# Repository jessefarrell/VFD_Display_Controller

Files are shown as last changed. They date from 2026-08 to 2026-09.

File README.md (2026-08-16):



<!-- PROJECT LOGO -->
<br />
<div align="center">
  <a href="https://github.com/othneildrew/Best-README-Template">
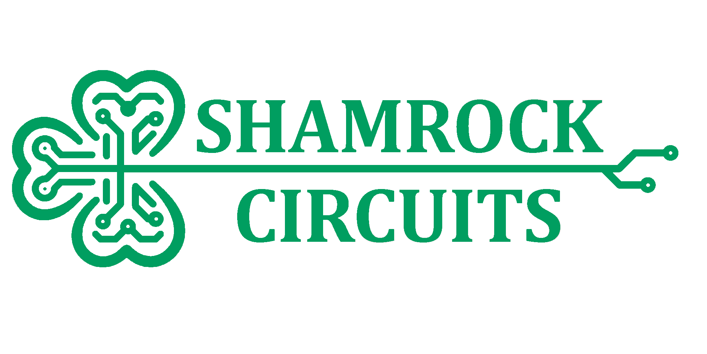
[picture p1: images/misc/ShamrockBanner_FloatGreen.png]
    
  </a>

  <h1 align="center">VFD Module Controller - REV00</h1>

  <p align="center">
    The <a href="https://ckm-content.se.com/ckmContent/sfc/servlet.shepherd/document/download/0691H00000GYmavQAD">Power Measurement, ACM 3710</a> was a power meter released in 1989 which was discontinued in the "early 2000s".<br />
    These meters used an interesting, semi-custom, 20 character, 14 segment, Vacuum Fluorescent Display.
    <br />
    I have five of these VFD modules floating around my parts bin... so I made this controller board to interfce with them.
    <br />
    <br />
    <strong>STATUS - IN PROGRESS</strong>
    <br />
    <a href="https://youtube.com">View Demo</a> [PENDING]

  </p>
</div>

## Introduction
<!-- High level overview of what the project is and does -->
This VFD module controller was designed around a VFD module that was originally integrated into the <a href="https://ckm-content.se.com/ckmContent/sfc/servlet.shepherd/document/download/0691H00000GYmavQAD">ACM 3710</a>. Exact model numbers of the module seem to vary, but as far as I can tell they are all interchangeable. This module is the **ISE Electronics Corp, FU209SCPB-S4A** or **FU209SCPB-T60A**, and they seem to be a custom (undocumented) model that is similar to  **CU209SCPB-T20A**. The purpose of this project is to convert the VFD modules parallel bus interface into something configurable over USB, and to possible develop a few applications for the display.
<p align="center">
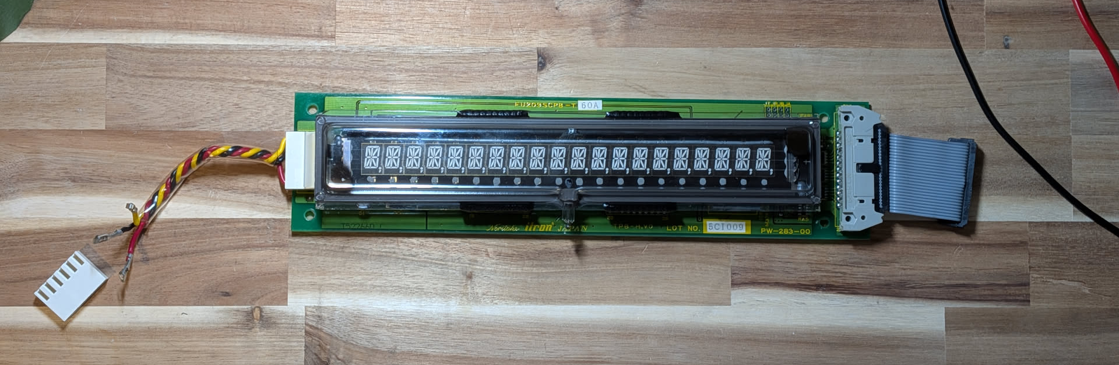
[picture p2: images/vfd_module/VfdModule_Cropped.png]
  
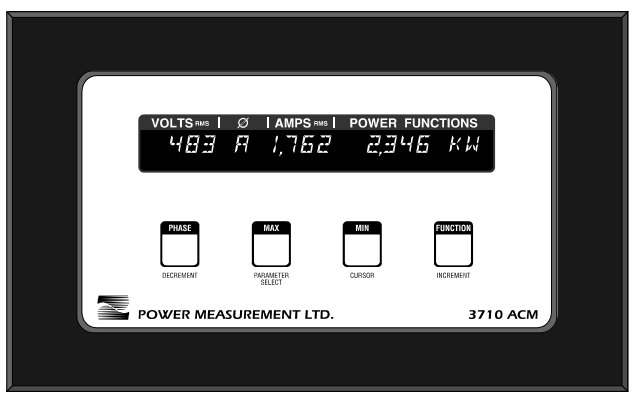
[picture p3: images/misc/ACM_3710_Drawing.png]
ACM 3710
  
</p>

## Motivation
<!-- Why I bothered making this -->
I'm a sucker for 7-segment displays and other interesting displays in general. So 14 segments on a VFD easily got my attention from the bin. A short dumpster dive later I found myself the proud owner of 5 VFD modules. All of the hard work of interfacing with the display is managed by the module, but I still need a way of controlling the 8bit data bus from the comfort of my desk. The fact that so much of the work has been offloaded onto the VFD module itself, makes this whole thing a good candidate for a "quick weekend project"...

## Features
- USB Serial Control
- Command Line Interface
- Write Character or String
- Shift Displayed String
- Delete Character
- Clear Screen

## How it Works
<!-- IMAGE: Block diagram -->
This project could, in theory, be as simple as a microcontroller driving the various I/O pins of the VFD module. The module itself consumes about 430-460mA during normal operation, from a single 5V power input (the module then converts that to a higher voltage for the VFD), leaving just enough headroom in the 500mA (5 unit load) USB spec to power the controller board I'm designing. Some flavour of AVR microcontroller would have been a good fit here, but my bin full of Pi Pico's is looking for a project, meaning I'll need some logic level translators. I also decided to include an optional barrel jack power input incase I want to stack multiple VFD modules together, or if the USB port isn't able to provide the 500mA.
<br />
<br />
Instead of providing a block diagram, this project is small enough to just review the schematic (shown below).
<p align="center">
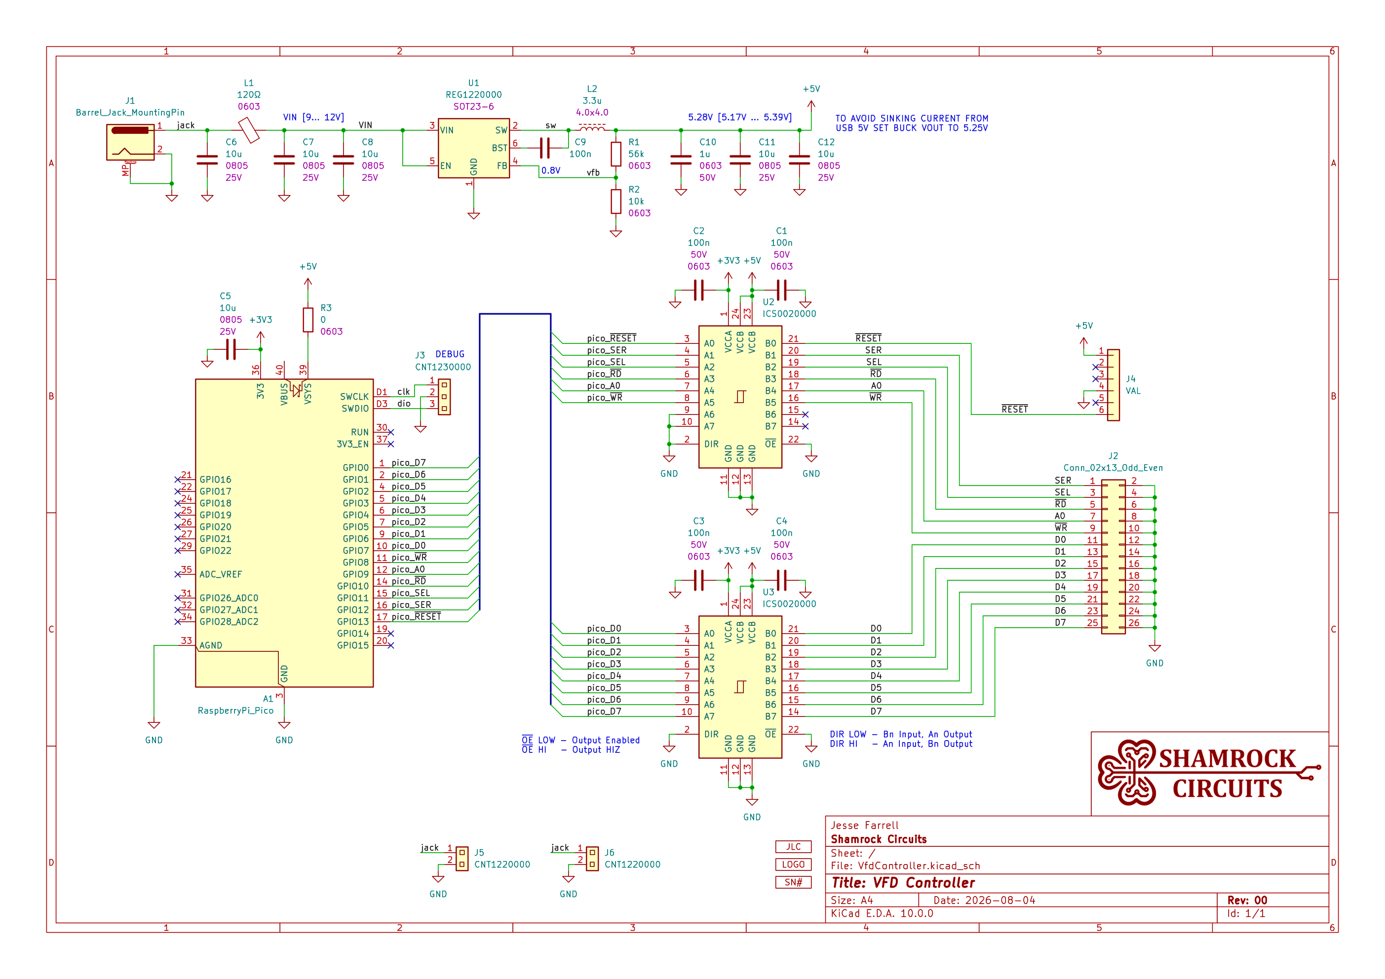
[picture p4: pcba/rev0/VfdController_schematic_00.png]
Schematic Image
  
</p>

## Gallery

<!-- IMAGE: 2-3 supporting shots — schematic snippet, PCB layout, alternate angle render -->
<p float="left">
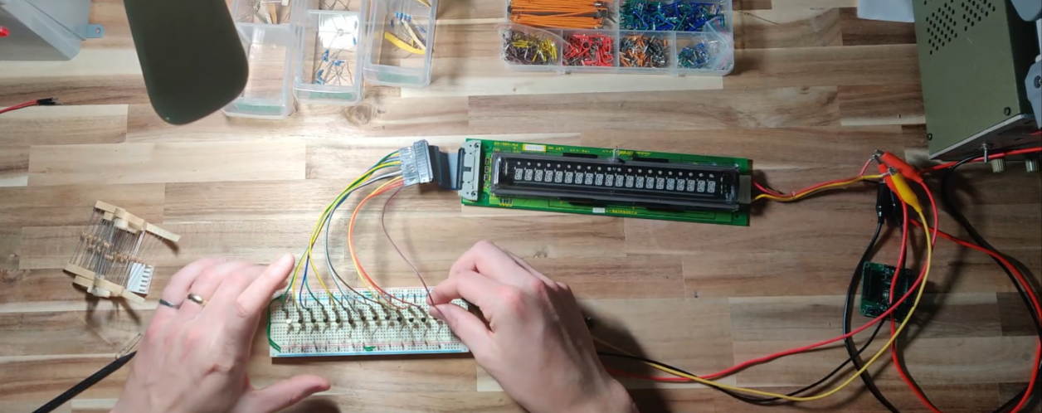
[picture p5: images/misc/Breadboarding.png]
  
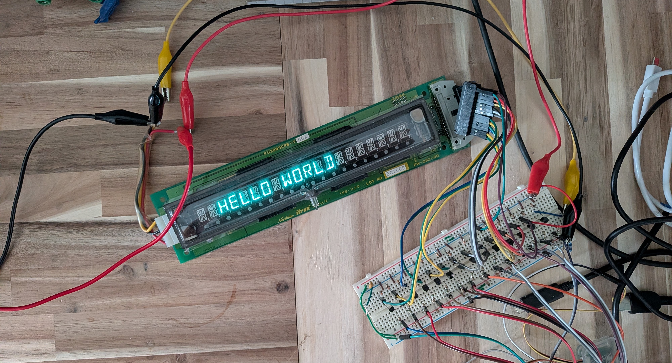
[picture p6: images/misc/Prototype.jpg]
PCB bottom layout
  
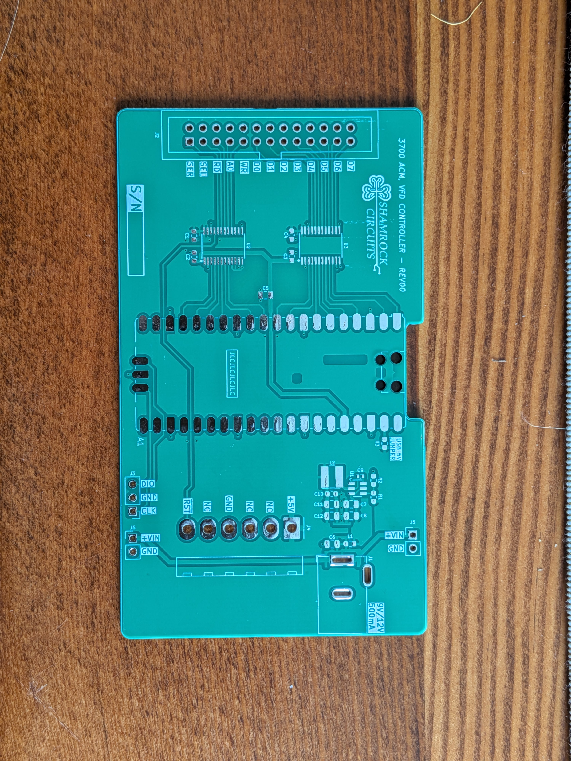
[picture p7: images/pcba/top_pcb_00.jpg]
  
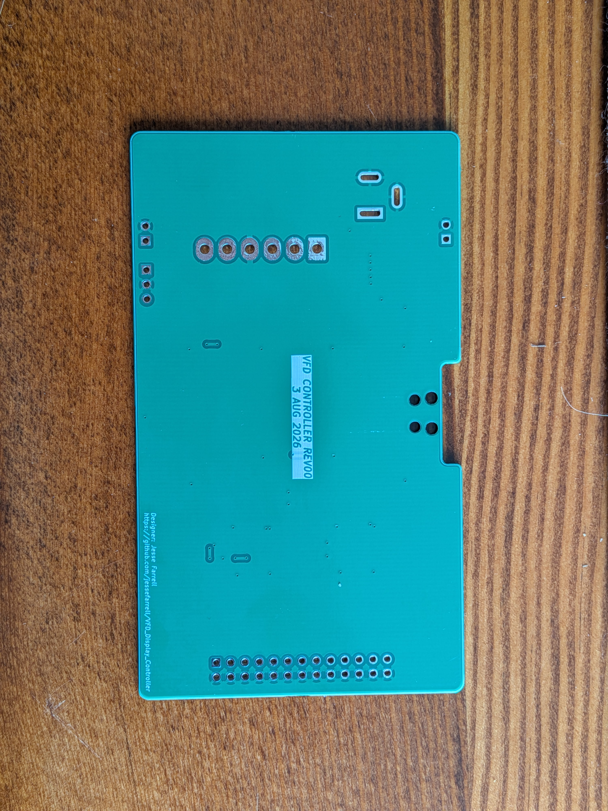
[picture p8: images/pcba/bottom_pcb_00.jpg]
  
</p>

## Status
I received PCBs 8/16/2026, and I recently ordered the connectors. This project will probably be closed later this month.

## License



---

Designed by Jesse Farrell — [info@shamrockcircuits.com](mailto:info@shamrockcircuits.com)

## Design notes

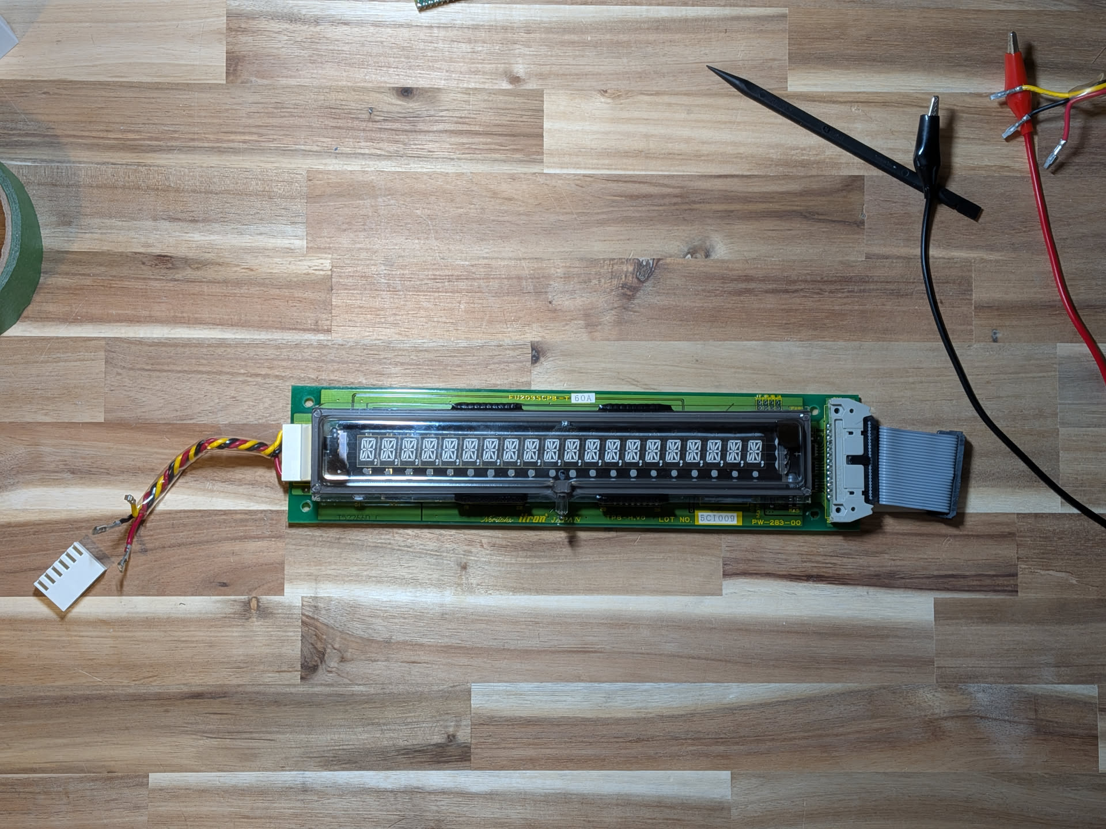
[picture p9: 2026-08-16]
images/vfd_module/VfdModule.png

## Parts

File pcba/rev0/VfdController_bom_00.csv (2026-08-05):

IPN | Reference | Qty | Value | Exclude from BOM | Footprint | Package | MFN_1 | MPN_1 | LCSC_1
N/A | A1 | 1 | RaspberryPi_Pico |  | Module:RaspberryPi_Pico_SMD_HandSolder
CAP-000-1042 | C1,C2,C3,C4 | 4 | 100n |  | 0-CAP:FTP-CAP-0001 | 603 | Samsung | CC0603KRX7R9BB104 | C14663, BASIC
CAP-007-1061 | C5,C6,C7,C8,C11,C12 | 6 | 10u |  | 0-CAP:FTP-CAP-0002 | 805 | Samsung | CL21A106KAYNNNE | C15850
CAP-001-1042 | C9 | 1 | 100n |  | 0-CAP:FTP-CAP-0000 | 402 | Samsung | CL05B104KB54PNC | C307331
CAP-003-1051 | C10 | 1 | 1u |  | 0-CAP:FTP-CAP-0001 | 603 | Samsung | CL10A105KB8NNNC | C15849
N/A | J1 | 1 | Barrel_Jack_MountingPin |  | Connector_BarrelJack:BarrelJack_GCT_DCJ200-10-A_Horizontal
N/A | J2 | 1 | Conn_02x13_Odd_Even |  | Connector_IDC:IDC-Header_2x13_P2.54mm_Vertical
CNT-123-0000 | J3 | 1 | CNT1230000 |  | 0-CNT:FTP-CNT-0008 |  | Molex | 22284030 | C587036, EXT
N/A | J4 | 1 | VAL |  | Connector_Molex:Molex_KK-396_A-41792-0006_1x06_P3.96mm_Horizontal
CNT-122-0000 | J5,J6 | 2 | CNT1220000 |  | 0-CNT:FTP-CNT-0007 |  | Molex | 22284020 | C234182, EXT
IND-203-1202 | L1 | 1 | 120Ω |  | 0-IND:FTP-IND-0002 | 603 | Murata | BLM18PG121SN1D | C14709
IND-002-3304 | L2 | 1 | 3.3u |  | 0-IND:FTP-IND-0000 | 4.0x4.0 | Vishay | VLS4020CX-3R3M-H | C6745793
RES-006-5604 | R1 | 1 | 56k |  | 0-RES:FTP-RES-0001 | 603 | Stackpole Electronics | RNCF0603BTE56K0 | C3958730
RES-006-1004 | R2 | 1 | 10k |  | 0-RES:FTP-RES-0001 | 603 | Stackpole Electronics | RNCF0603BTE10K0 | C346560
RES-000-0000 | R3 | 1 | 0 |  | 0-RES:FTP-RES-0001 | 603 | UNI-ROYAL | 0603WAF0000T5E | C21189, BASIC
REG-122-0000 | U1 | 1 | REG1220000 |  | 1-PACKAGES:Generic-SOT23-6 | SOT23-6 | Diodes Inc. | AP62150WU* | C3194237
ICS-002-0000 | U2,U3 | 2 | ICS0020000 |  | 1-PACKAGES:Generic-TSSOP-24_4.4x7.8mm_P0.65mm | TSSOP-24 (4.40mm) | Nexperia | 74LVC4245APW,118 | C6091, EXT

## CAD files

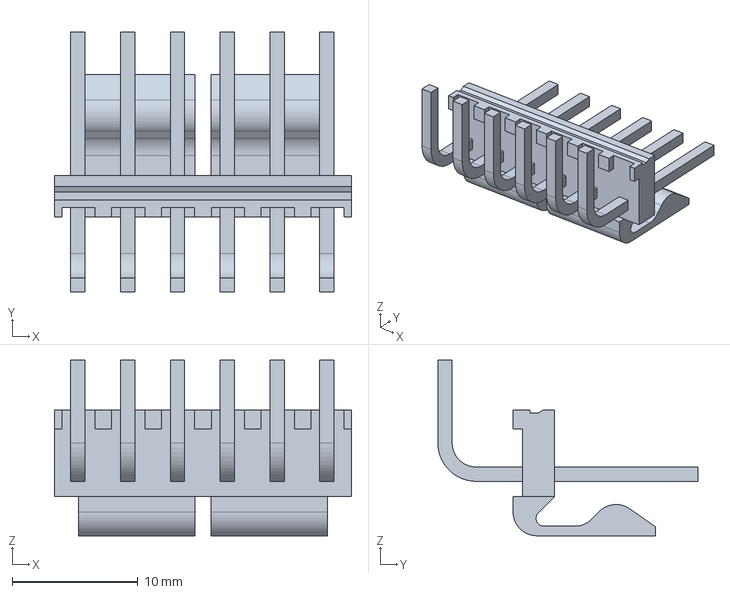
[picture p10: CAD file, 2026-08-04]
3dmodels/Components/6Pin_Molex.stp
23.6 x 20.7 x 14.0 mm

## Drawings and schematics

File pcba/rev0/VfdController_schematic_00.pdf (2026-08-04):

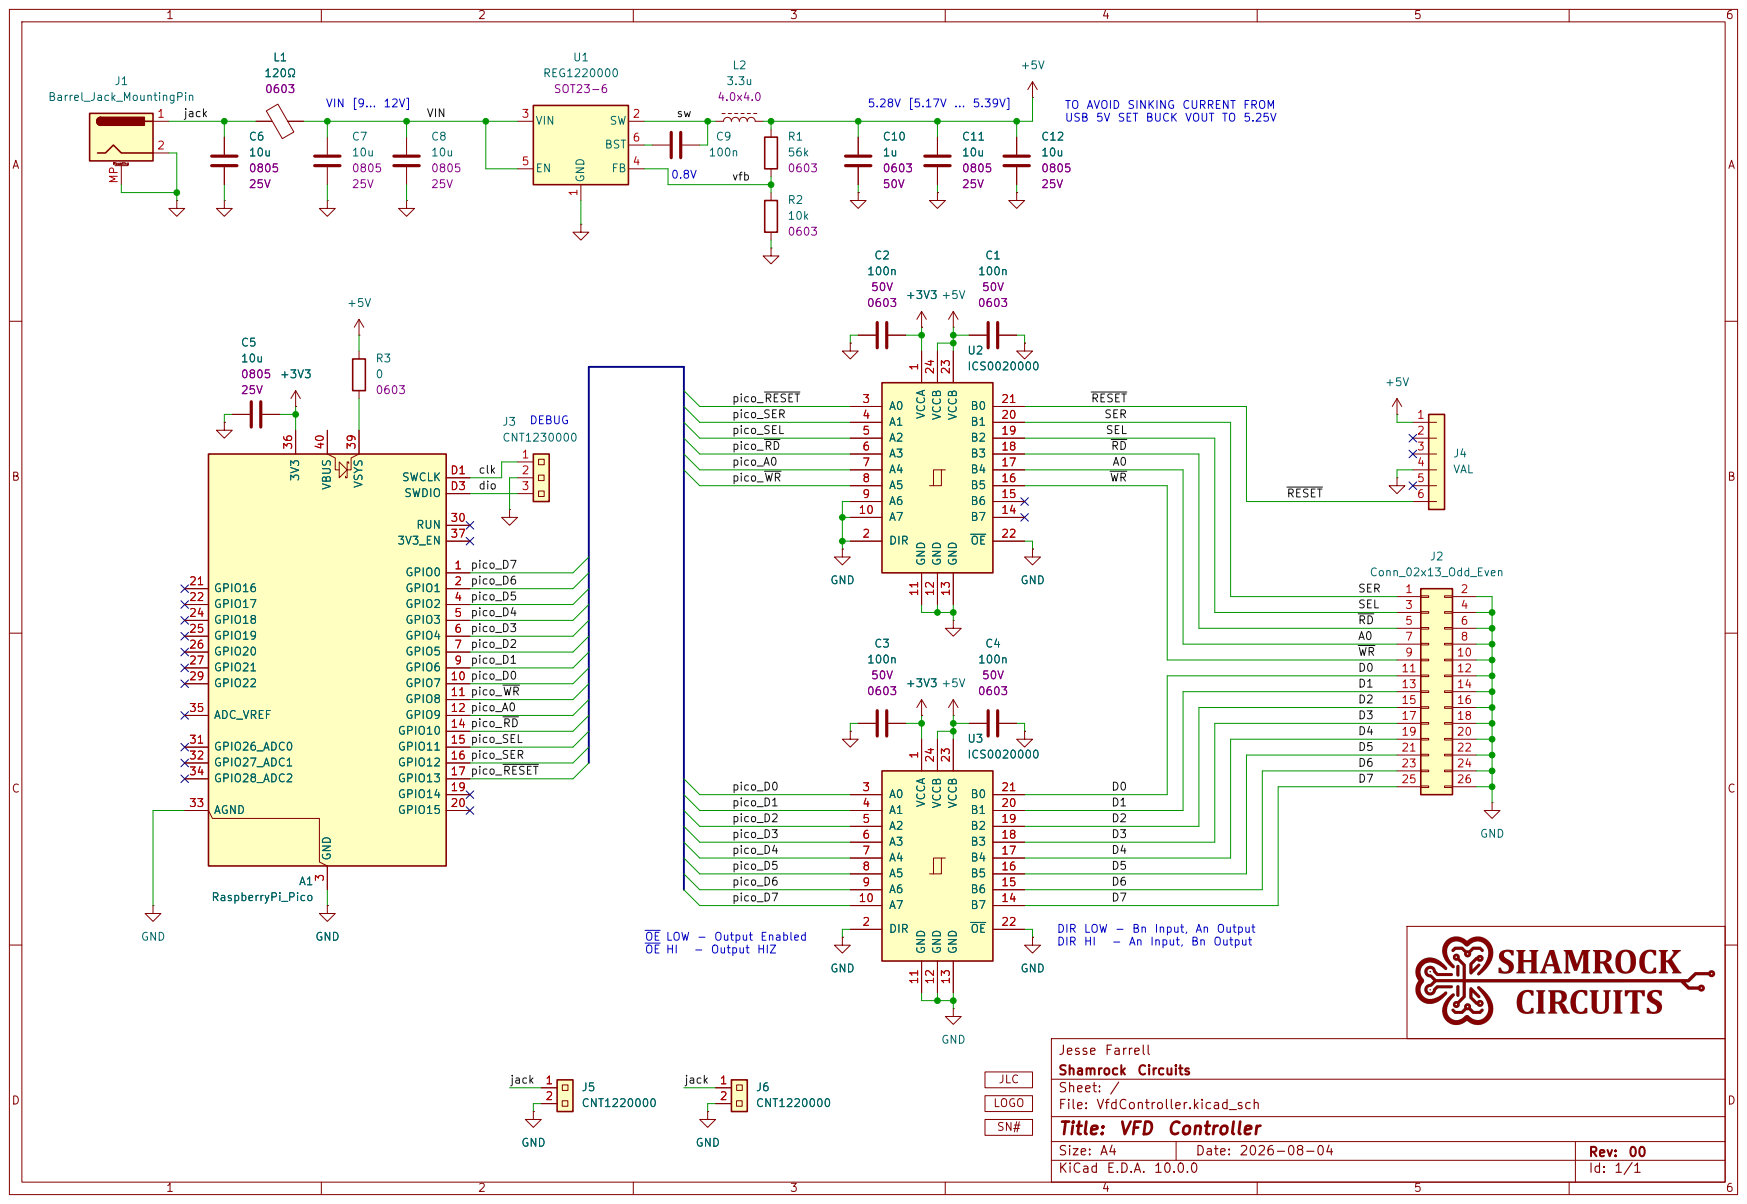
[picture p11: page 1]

TO AVOID SINKING CURRENT FROM
USB 5V SET BUCK VOUT TO 5.25V

13 | 14
15 | 16
17 | 18
19 | 20
21 | 22
23 | 24

DIR LOW - Bn Input, An Output

Size: A4 | Rev: 00

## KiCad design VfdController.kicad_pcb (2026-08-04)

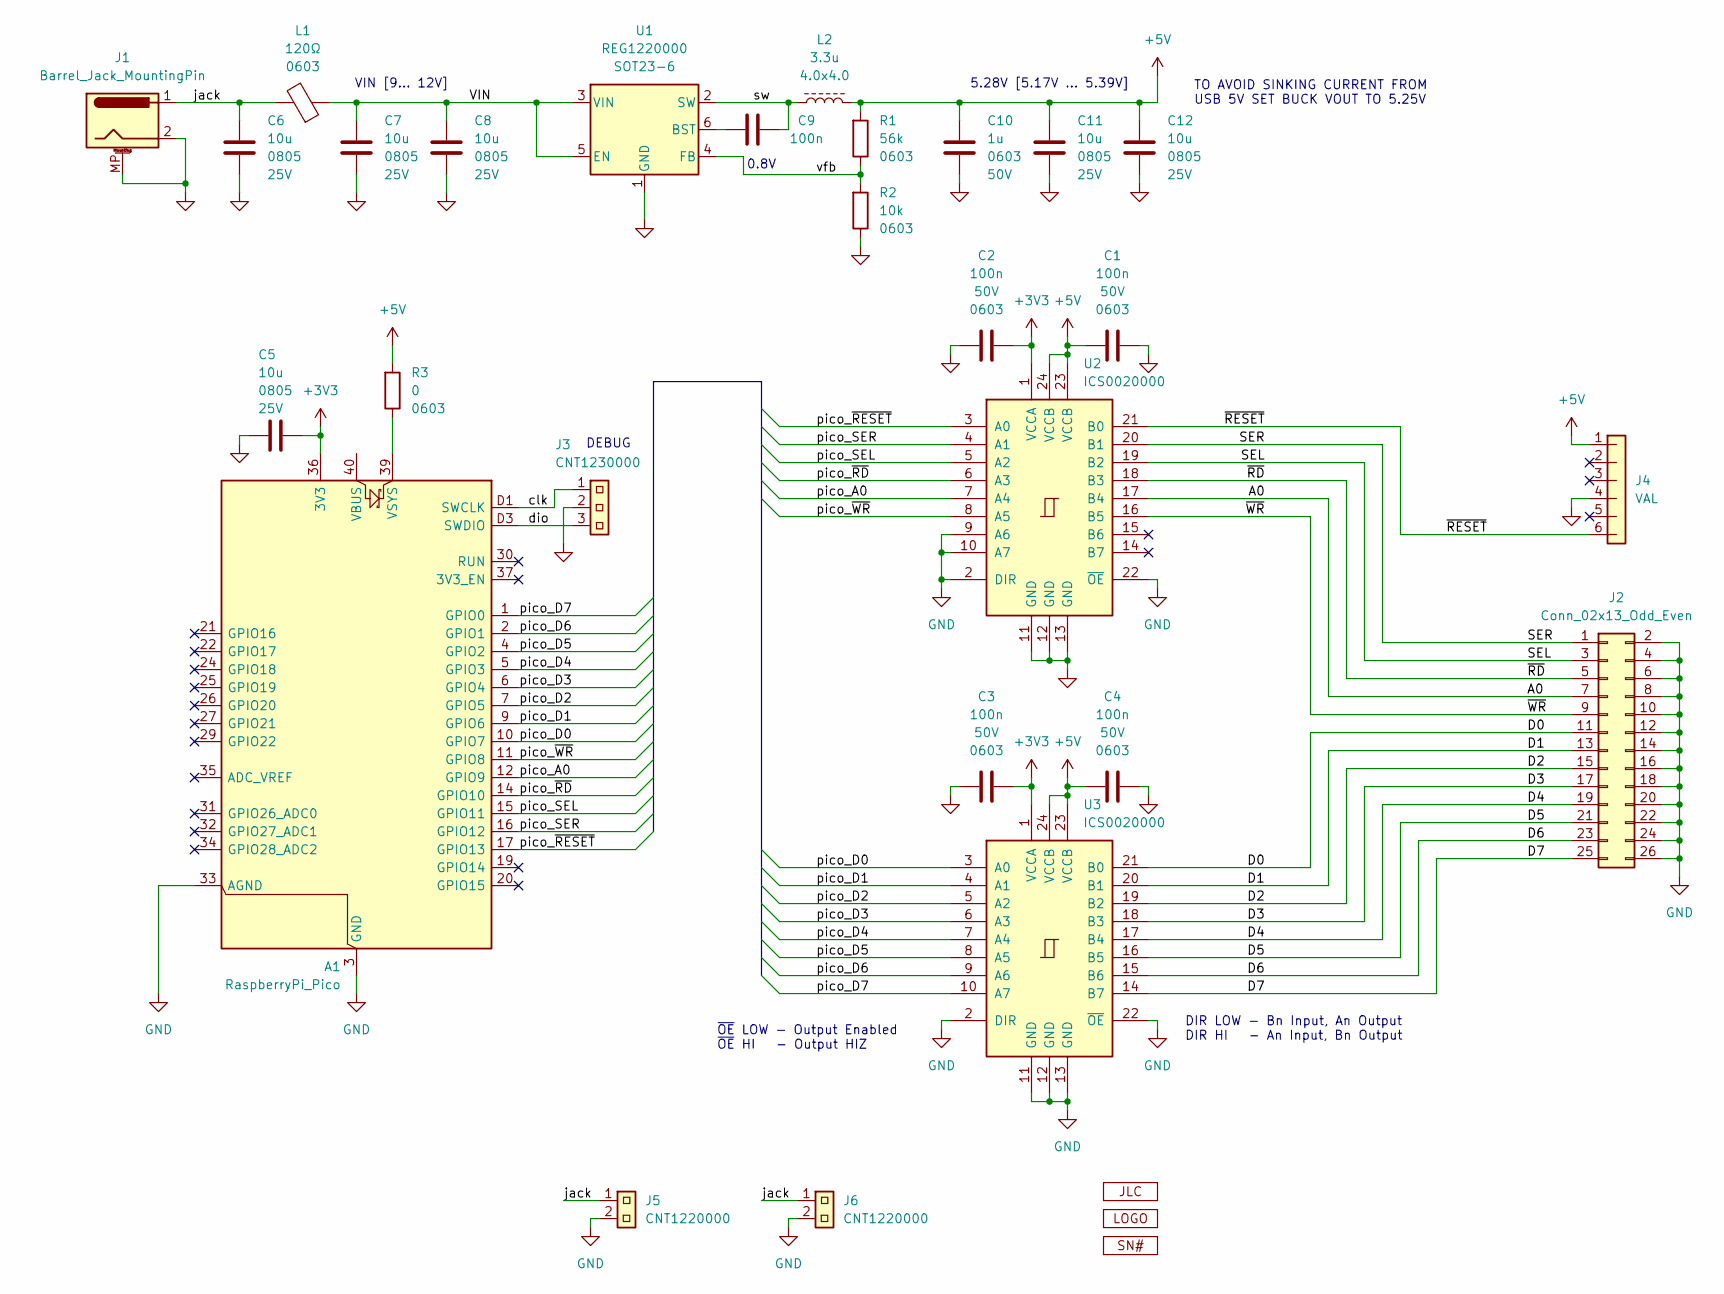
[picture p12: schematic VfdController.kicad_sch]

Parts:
A1: RaspberryPi_Pico; RaspberryPi_Pico_SMD_HandSolder
C1, C2, C3, C4: 100n; FTP-CAP-0001; Voltage Rating 50V; MPN_1 CC0603KRX7R9BB104; LCSC_1 C14663, BASIC
C5, C6, C7, C8, C11, C12: 10u; FTP-CAP-0002; Voltage Rating 25V; MPN_1 CL21A106KAYNNNE; LCSC_1 C15850
C9: 100n; FTP-CAP-0000; Voltage Rating 50V; MPN_1 CL05B104KB54PNC; LCSC_1 C307331
C10: 1u; FTP-CAP-0001; Voltage Rating 50V; MPN_1 CL10A105KB8NNNC; LCSC_1 C15849
G1: FTP-MRK-0002b
G2: FTP-MRK-0000
G3: FTP-MRK-0003
J1: Barrel_Jack_MountingPin; BarrelJack_GCT_DCJ200-10-A_Horizontal
J2: Conn_02x13_Odd_Even; IDC-Header_2x13_P2.54mm_Vertical
J3: CNT1230000; FTP-CNT-0008; MPN_1 22284030; LCSC_1 C587036, EXT
J4: VAL; Molex_KK-396_A-41792-0006_1x06_P3.96mm_Horizontal
J5, J6: CNT1220000; FTP-CNT-0007; MPN_1 22284020; LCSC_1 C234182, EXT
L1: 120Ω; FTP-IND-0002; MPN_2 742792625; LCSC_1 C14709
L2: 3.3u; FTP-IND-0000; MPN_3 AWVF004040183R3M00; LCSC_3 C17220294
R1: 56k; FTP-RES-0001; MPN_1 RNCF0603BTE56K0; LCSC_1 C3958730
R2: 10k; FTP-RES-0001; MPN_1 RNCF0603BTE10K0; LCSC_1 C346560
R3: 0; FTP-RES-0001; MPN_1 0603WAF0000T5E; LCSC_1 C21189, BASIC
U1: REG1220000; Generic-SOT23-6; MPN_1 AP62150WU*; LCSC_1 C3194237
U2, U3: ICS0020000; Generic-TSSOP-24_4.4x7.8mm_P0.65mm; MPN_1 74LVC4245APW,118; LCSC_1 C6091, EXT

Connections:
+3V3: A1.36 (3V3), C2.2, C3.2, C5.1, U2.1 (VCCA), U3.1 (VCCA)
+5V: C1.1, C4.1, C10.1, C11.1, C12.1, J4.1, L2.2, R1.1, R3.1, U2.23 (VCCB), U2.24 (VCCB), U3.23 (VCCB), U3.24 (VCCB)
/A0: J2.7, U2.17 (B4)
/D0: J2.11, U3.21 (B0)
/D1: J2.13, U3.20 (B1)
/D2: J2.15, U3.19 (B2)
/D3: J2.17, U3.18 (B3)
/D4: J2.19, U3.17 (B4)
/D5: J2.21, U3.16 (B5)
/D6: J2.23, U3.15 (B6)
/D7: J2.25, U3.14 (B7)
/SEL: J2.3, U2.19 (B2)
/SER: J2.1, U2.20 (B1)
/VIN: C7.1, C8.1, L1.1, U1.3 (VIN), U1.5 (EN)
/clk: A1.D1 (SWCLK), J3.1
/dio: A1.D3 (SWDIO), J3.3
/jack: C6.1, J1.1, J5.1, J6.1, L1.2
/pico_A0: A1.12 (GPIO9), U2.7 (A4)
/pico_D0: A1.10 (GPIO7), U3.3 (A0)
/pico_D1: A1.9 (GPIO6), U3.4 (A1)
/pico_D2: A1.7 (GPIO5), U3.5 (A2)
/pico_D3: A1.6 (GPIO4), U3.6 (A3)
/pico_D4: A1.5 (GPIO3), U3.7 (A4)
/pico_D5: A1.4 (GPIO2), U3.8 (A5)
/pico_D6: A1.2 (GPIO1), U3.9 (A6)
/pico_D7: A1.1 (GPIO0), U3.10 (A7)
/pico_SEL: A1.15 (GPIO11), U2.5 (A2)
/pico_SER: A1.16 (GPIO12), U2.4 (A1)
/pico_~RD: A1.14 (GPIO10), U2.6 (A3)
/pico_~RESET: A1.17 (GPIO13), U2.3 (A0)
/pico_~WR: A1.11 (GPIO8), U2.8 (A5)
/sw: C9.1, L2.1, U1.2 (SW)
/vfb: R1.2, R2.1, U1.4 (FB)
/~RD: J2.5, U2.18 (B3)
/~RESET: J4.6, U2.21 (B0)
/~WR: J2.9, U2.16 (B5)
GND: A1.3 (GND), A1.8 (GND), A1.13 (GND), A1.18 (GND), A1.23 (GND), A1.28 (GND), A1.33 (AGND), A1.38 (GND), A1.D2 (GND), C1.2, C2.1, C3.1, C4.2, C5.2, C6.2, C7.2, C8.2, C10.2, C11.2, C12.2, J1.2, J1.MP (MountPin_MP), J2.2, J2.4, J2.6, J2.8, J2.10, J2.12, J2.14, J2.16, J2.18, J2.20, J2.22, J2.24, J2.26, J3.2, J4.4, J5.2, J6.2, R2.2, U1.1 (GND), U2.2 (DIR), U2.9 (A6), U2.10 (A7), U2.11 (GND), U2.12 (GND), U2.13 (GND), U2.22 (~OE), U3.2 (DIR), U3.11 (GND), U3.12 (GND), U3.13 (GND), U3.22 (~OE)
unnamed: A1.39 (VSYS), R3.2
unnamed: C9.2, U1.6 (BST)

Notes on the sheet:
DIR LOW - Bn Input, An Output DIR HI - An Input, Bn Output
5.28V [5.17V ... 5.39V]
DEBUG
0.8V
~{OE} LOW - Output Enabled ~{OE} HI - Output HIZ
TO AVOID SINKING CURRENT FROM USB 5V SET BUCK VOUT TO 5.25V
VIN [9... 12V]

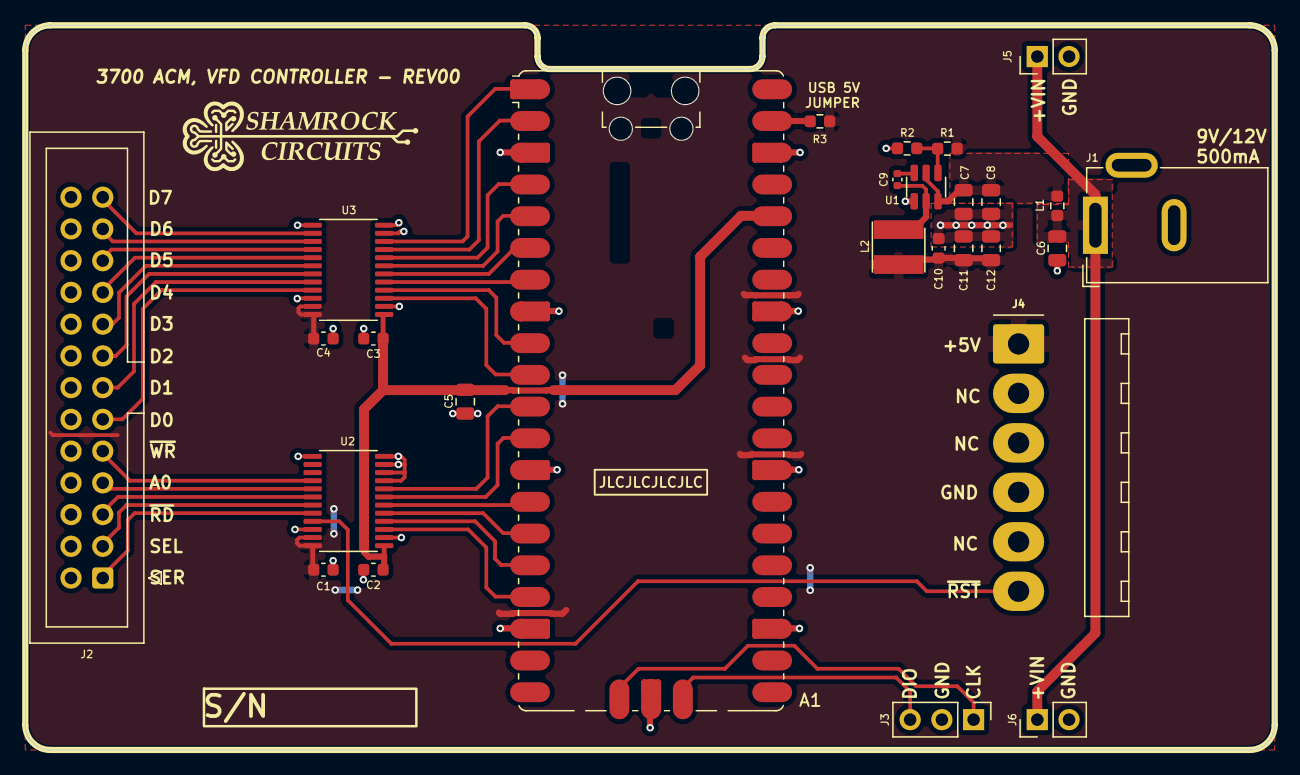
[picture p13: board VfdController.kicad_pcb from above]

Board: 2 copper layers, 100.0 x 58.0 mm, 30 parts (0 on the bottom side), 39 nets.

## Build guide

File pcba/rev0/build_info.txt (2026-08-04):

__General Notes__
04/08/2026 - Ordered 10x PCBA. 1oz copper, lead free HASL, 1.6mm, ect.

__Details__
PCB FAB	--------> JLCPCB
Layers ---------> 2L
Stackup Used ---> Default

__Build Table__
|Build Date	| BOM Used	| Comments	  				|
|---|---|---|
|04/08/2026	| n/a		| Hand assembling these boards.			|
|dd/mm/yy	| xxx.csv	| build notes...				|
|---------------|---------------|-----------------------------------------------|

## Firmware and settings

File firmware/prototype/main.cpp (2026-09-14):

/**
 * Copyright (c) 2020 Raspberry Pi (Trading) Ltd.
 *
 * SPDX-License-Identifier: BSD-3-Clause
 */

#include "pico/stdlib.h"
#include "pico/stdio.h"
#include "config.h"
#include "vfd.h"
#include "clock.h"
#include "test_display.h"
#include "animation.h"
#include <stdio.h>

// Single global instance, shared by whichever app the user selects below.
Vfd vfd(SETUP_HOLD_TIME_US);

/**
 * @brief Blocking read of one character from stdin, echoed back to console.
 */
static char read_char(void) {
    int c = getchar_timeout_us(UINT32_MAX);  // block indefinitely

    if (c == PICO_ERROR_TIMEOUT) {
        return '\0';  // shouldn't happen with UINT32_MAX, but just in case
    }

    putchar((char)c);
    return (char)c;
}

static void print_app_menu(void) {
    printf("\n--- VFD Launcher ---\n");
    printf("  [1] Clock\n");
    printf("  [2] Display Test Harness\n");
    printf("  [3] Animation\n");
    printf("Select an application: ");
}

int main() {
    stdio_init_all();
    sleep_ms(2000);  // give USB serial time to enumerate before first prints

    vfd.init();

    // Redisplay the menu every time an app exits (Esc/Ctrl+C) or an
    // invalid key was pressed.
    while (true) {
        print_app_menu();
        char choice = read_char();
        printf("\n");

        switch (choice) {
            case '1':
                printf("-> Starting Clock\n");
                run_clock_app(vfd);
                break;

            case '2':
                printf("-> Starting Display Test Harness\n");
                run_display_test_app(vfd);
                break;

            case '3':
                printf("-> Starting Animation\n");
                run_animation_app(vfd);
                break;

            default:
                printf("Unrecognized selection: '%c'. Please choose 1, 2, or 3.\n", choice);
                break;
        }

        // Start the next menu prompt from a clean display, whether an app
        // just exited or the selection was invalid.
        vfd.clear_screen();
    }
}

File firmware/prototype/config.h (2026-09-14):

#ifndef CONFIG_H
#define CONFIG_H

/* =====================================================================
 * VFD Module Configuration
 * Target: Raspberry Pi Pico (RP2040)
 * Module: VFD module FU209SCPB-T60A harvested from ACM 3710 energy meter
 * Board: VfdController (Shamrock Circuits) - Pico signals are routed
 *        through a pair of 74LVC4245 (U2/U3) level translators before
 *        reaching the 6-pin power header and 26-pin data header.
 * =====================================================================
 *
 * ---------------------------------------------------------------------
 * 6-Pin Power Header (J4)
 * ---------------------------------------------------------------------
 *   Pin 1 -> +5V        (power supply, not a Pico GPIO)
 *   Pin 4 -> GND        (ground, not a Pico GPIO)
 *   Pin 6 -> -RESET     -> U2 (level translator) -> Pico GP13
 *
 * ---------------------------------------------------------------------
 * 26-Pin Data Header (J2)
 * ---------------------------------------------------------------------
 *   All even pins (2,4,6,...,26) -> GND
 *
 *   Pin 1  -> SERIAL    -> U3 -> Pico GP0
 *   Pin 3  -> SEL       -> U3 -> Pico GP1
 *   Pin 5  -> -RD       -> U3 -> Pico GP2
 *   Pin 7  -> A0        -> U3 -> Pico GP3
 *   Pin 9  -> -WR       -> U3 -> Pico GP4
 *   Pin 11 -> D0        -> U3 -> Pico GP5
 *   Pin 13 -> D1        -> U3 -> Pico GP6
 *   Pin 15 -> D2        -> U3 -> Pico GP7
 *   Pin 17 -> D3        -> U2 -> Pico GP8
 *   Pin 19 -> D4        -> U2 -> Pico GP9
 *   Pin 21 -> D5        -> U2 -> Pico GP10
 *   Pin 23 -> D6        -> U2 -> Pico GP11
 *   Pin 25 -> D7        -> U2 -> Pico GP12
 *
 * Note: signals prefixed with 'n' (e.g. VFD_nRESET, VFD_nRD, VFD_nWR)
 * are active-low, matching the "-" notation in the source pinout.
 * =====================================================================
 */

 #define SETUP_HOLD_TIME_US 50
 

/* ---- Control / Status Pins ---- */
#define VFD_nRESET   13   /* -RESET, from 6-pin power header (J4), pin 6 */
#define VFD_SERIAL   0    /* SERIAL, unused on ACM 3710, data header (J2) pin 1 */
#define VFD_nSEL      1    /* -SEL, data header (J2) pin 3 */
#define VFD_nRD      2    /* -RD, data header (J2) pin 5 */
#define VFD_A0       3    /* A0, data header (J2) pin 7 */
#define VFD_nWR      4    /* -WR, data header (J2) pin 9 */

/* ---- Data Bus Pins (D0-D7) ---- */
#define VFD_D0       5    /* data header (J2) pin 11 */
#define VFD_D1       6    /* data header (J2) pin 13 */
#define VFD_D2       7    /* data header (J2) pin 15 */
#define VFD_D3       8    /* data header (J2) pin 17 */
#define VFD_D4       9    /* data header (J2) pin 19 */
#define VFD_D5       10   /* data header (J2) pin 21 */
#define VFD_D6       11   /* data header (J2) pin 23 */
#define VFD_D7       12   /* data header (J2) pin 25 */

#endif /* CONFIG_H */

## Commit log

2026-08-04 Ordered REV00 PCB's x10
    [VfdController.kicad_pcb, VfdController.kicad_sch, VfdController_bom_00.csv]
2026-08-06 Early prototype firmware.
2026-10-22 Gerber Upload

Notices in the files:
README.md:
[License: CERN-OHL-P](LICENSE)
